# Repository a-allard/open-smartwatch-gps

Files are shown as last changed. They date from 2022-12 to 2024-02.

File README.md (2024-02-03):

# Open-Smartwatch KiCAD files

Repo for kicad schematic, board and gerber files. This project is in development and is not ready for release.

If all you want to know is how to build skip down to [Build Info](##Build Info)

#### Forking to move forward

The [original project ](https://github.com/Open-Smartwatch/open-smartwatch-gps) seems to have lost some momentum on development.  There is an [issue here](https://github.com/Open-Smartwatch/open-smartwatch-gps/issues/10) to discuss merging these changes into the original project.  One of the goals of this fork and update is to minimize any serious changes to [the os](https://github.com/Open-Smartwatch/open-smartwatch-os).  If all goes well, the OS should be able to be dropped on here with little to no modifications.  (that is the goal time will tell for sure.)

Right now this is a 2 layer design.  If this works it will greatly reduce the overall cost.  Have to see how this performs.

## Tools

To view/modify the files from this repository install [KiCAD](https://kicad.org).  You'll need version 7.0 or higher.  This will be bumped in Janurary of 2024 to KiCad 8.0.

All footprints, schematic symbols and 3d models should be self contained winthin the project.  This means you should be able to open the kicad project anywhere with or without the default kicad libraries and play with things without worry about missing pieces.

## Schematic
Updated as of 10/20/2023.  May change but if it does it should be minor changes.

Update on 1/7/2024.... Happy New Year to all!  Been quite for awhile as getting boards built and tested took quite a while.  Found a few issues.  Working on fixing them before another spin.  Probably be respinning sometime around May...?

Schematic

## Plots

Top
Bottom

## Build Info

To get some raw PCBs the best way would be [pcbway](https://pcbway.com).  Once this project has been built and tested the design will be published on pcbway for anyone to order with a couple clicks.

Next you'll have to either build this yourself or get these fabricated.  If you want to get the boards fabricated pcbway does a decent job.  You'll have to export the position files and put the BOM in pcbway format.

If you choose to solder these youself the smallest components are 0402 and QFNs.  Not the most friendly but can be done with a decent soldering iron.

### BOM

NOTE: **This is a preliminary BOM**  After testing this could change some.

[HTML BOM](https://github.com/a-allard/open-smartwatch-gps/blob/master/bom/OSW_GPS_Rev-4.0.html)  (best to download for a pretty view)

For actual parts you'll need
* [Digi-Key cart](https://www.digikey.com/short/5wz73v93) with most everything needed for a build of 1.
* [Display](https://www.buydisplay.com/1-28-inch-tft-lcd-display-240x240-round-circle-screen-for-smart-watch)
* A LiPo battery (Has not yet been selected but you should be able to power this from USB for initial debugging.  Any generic lipo should work just make sure the pinout works with the connector)

Total cost from DK ~$55.  The display is ~$15 including shipping.  With a battery this should bring the total BOM cost per watch to about ~$110 including boards from pcbway.com.  Note this is for a single watch but you'll have to order 5 boards from pcbway.com

Don't forget to get some decent fine solder while or solder paste as you will need it!

If you like this project, please consider supporting my open source projects through: "Buy Me A Coffee" (https://www.buymeacoffee.com/hwee)

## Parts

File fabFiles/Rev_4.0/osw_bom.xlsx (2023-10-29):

Item | Qty | Reference(s) | MPN | Manufacturer
1 | 1 | C1 | GRM155C81C105KE11J | Murata Electronics
2 | 1 | C2 | CC0402KPX5R6BB104 | YAGEO
3 | 4 | C3, C4, C10, C11 | CC0402MRX5R6BB475 | YAGEO
4 | 1 | C5 | CC0402KPX5R6BB104 | YAGEO
5 | 5 | C6, C7, C8, C15, C16 | CC0402KPX5R6BB104 | YAGEO
6 | 1 | C9 | CC0402KPX5R6BB104 | YAGEO
7 | 1 | C12 | CC0402KPX5R6BB104 | YAGEO
8 | 2 | C17, C18 | GRM155C81C105KE11J | Murata Electronics
9 | 1 | D1 | B0221USD-02D000154U1930
10 | 1 | J1 | B2B-EH-A
11 | 1 | J2 | MEM2067-02-180-00-A | GCT
12 | 1 | J3 | 2169890001 | Molex
13 | 1 | Q1 | T2N7002AK,LM
14 | 2 | R1, R19 | RC0402FR-07470RL | YAGEO
15 | 4 | R2, R3, R5, R12 | RC0402JR-071KL | YAGEO
16 | 12 | R4, R6, R7, R8, R9, R10, R11, R13, R16, R17, R20, R21 | RC0402DR-0710KL | YAGEO
17 | 1 | R14 | RC0402JR-0756KL | YAGEO
18 | 1 | R15 | RC0402FR-070RL | YAGEO
19 | 1 | R18 | RC0402FR-135K6L | YAGEO
20 | 4 | SW1, SW2, SW3, SW4 | EVQ-P7J01P | Panasonic Electronic Components
21 | 1 | U1 | L96-M33 | Quectel Wireless Solutions Co., Ltd
22 | 1 | U2 | TPS22933ARSET | Texas Instruments
23 | 1 | U3 | ESP32-MINI-1-N4 | Espressif Systems
24 | 1 | U4 | MCP73831T-2ACI/OT | Microchip Technology
25 | 2 | U5, U7 | MIC5504-3.3YMT-TZ | Microchip Technology
26 | 1 | U6 | FT234XD-R | FTDI
27 | 1 | U8 | 23K256T-I/SN | Microchip
28 | 1 | U9 | PCF85063ATL/1,118
29 | 1 | U10 | BMA400 | Bosch Sensortec
30 | 1 | U12 | IP4234CZ6,125
31 | 1 | U13 | BH1792GLC-E2

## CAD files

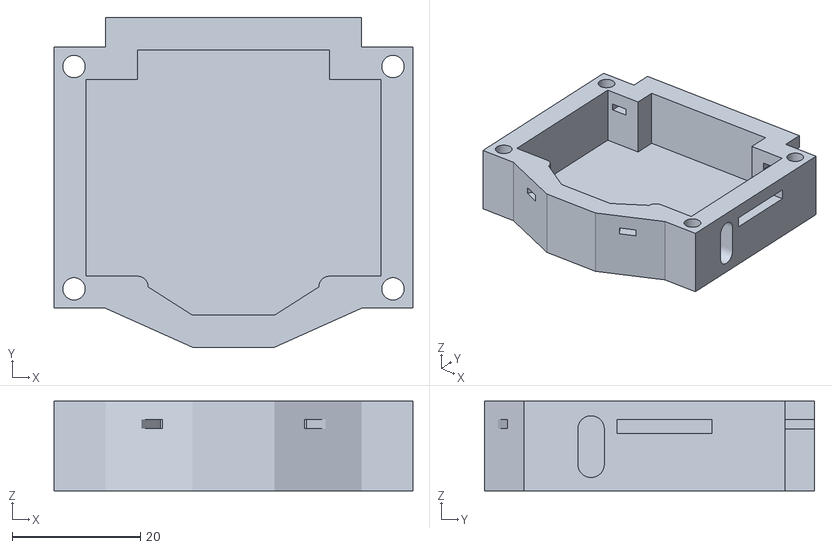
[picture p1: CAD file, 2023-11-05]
3dCAD_Source/mainCase.stl
56.0 x 51.4 x 14.0

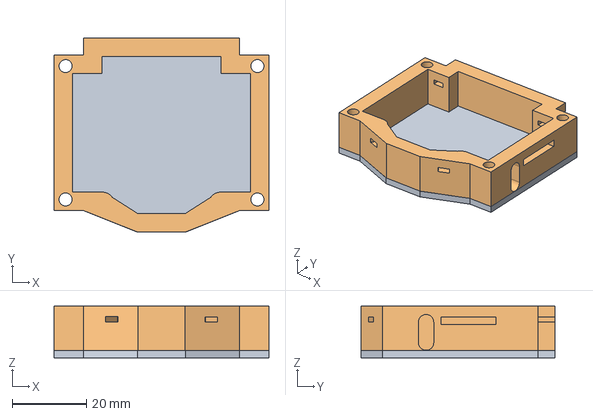
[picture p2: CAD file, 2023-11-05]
3dCAD_Source/watchCase.FCStd
58.0 x 52.4 x 14.0 mm

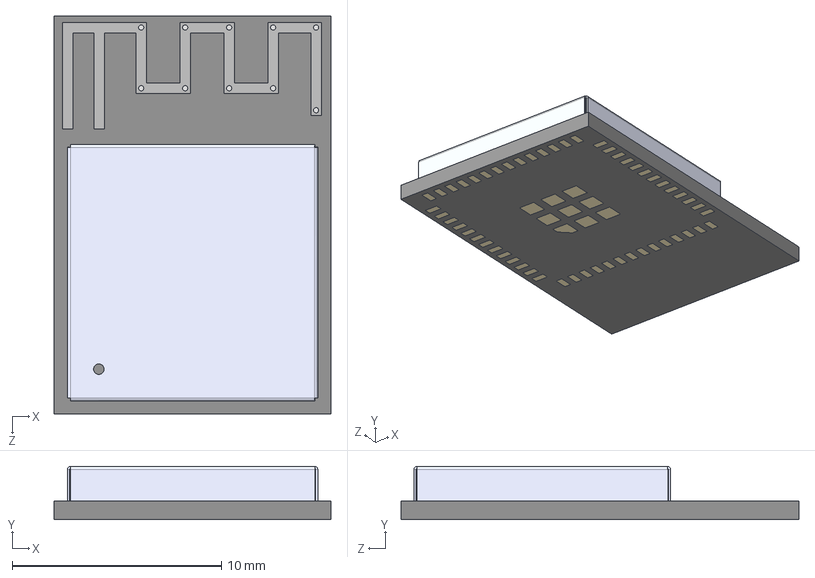
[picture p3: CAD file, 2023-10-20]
3dModels/ESP32-MINI-1-N4--3DModel-STEP-56544.STEP
13.2 x 2.55 x 19.0 mm

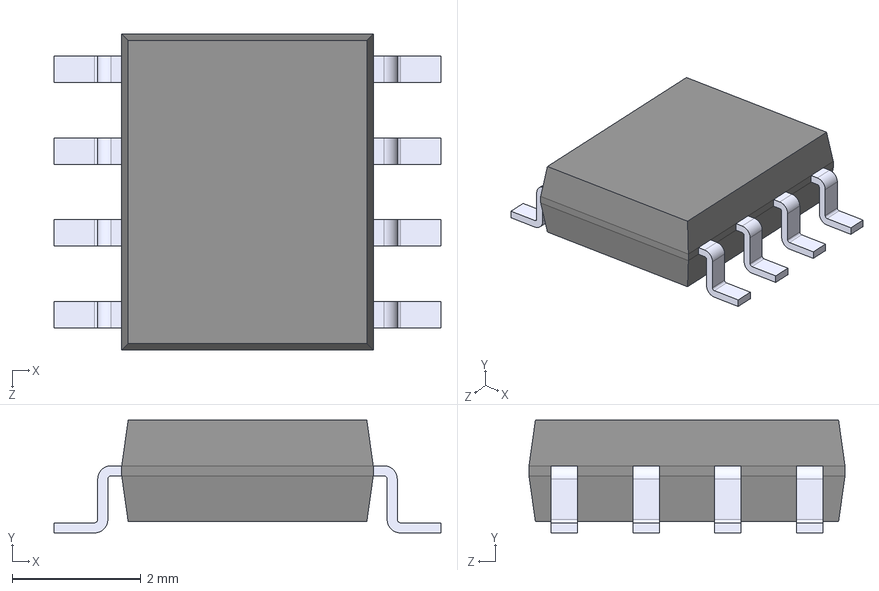
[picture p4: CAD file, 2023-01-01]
3dModels/23K256-I_SN.step
6.00 x 1.75 x 4.90 mm

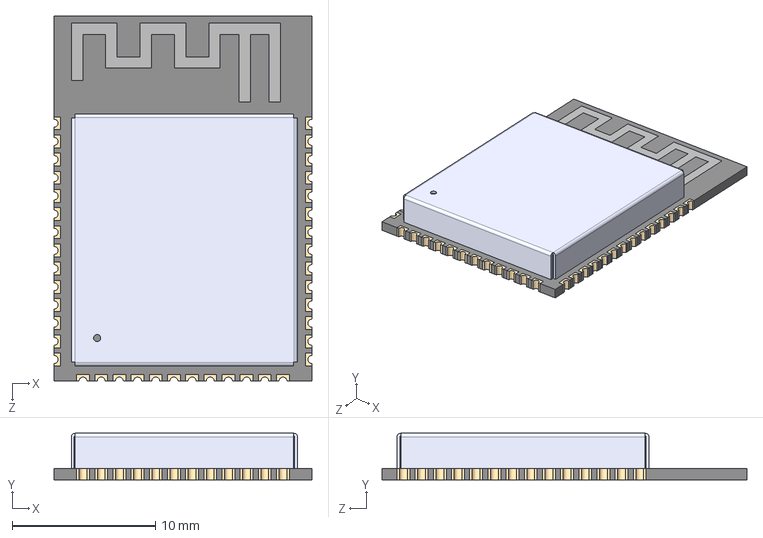
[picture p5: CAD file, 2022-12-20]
3dModels/ESP32-S3-WROOM-1.STEP
18.0 x 3.25 x 25.5 mm

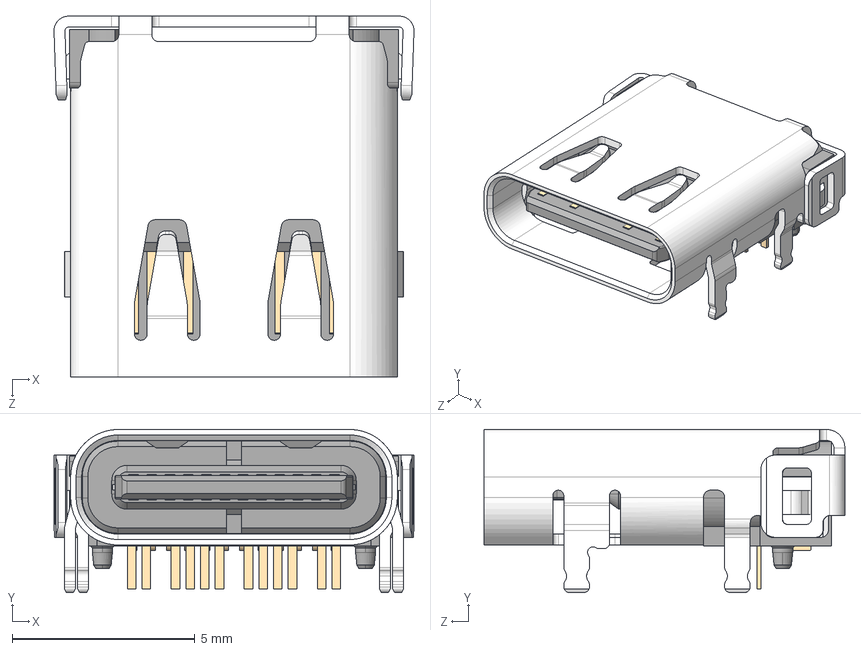
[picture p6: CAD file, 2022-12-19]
3dModels/USB4056-03-A_REVA.step
9.85 x 4.46 x 9.87 mm

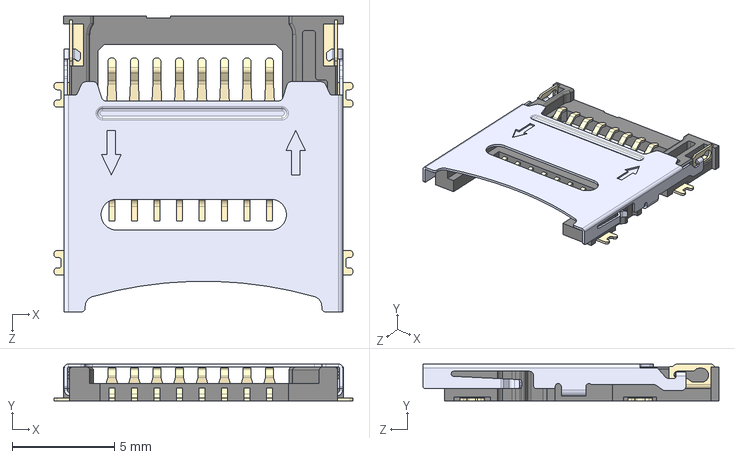
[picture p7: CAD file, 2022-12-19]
3dModels/MEM2067-02-180-00-A_REVB.step
14.6 x 1.80 x 14.5 mm

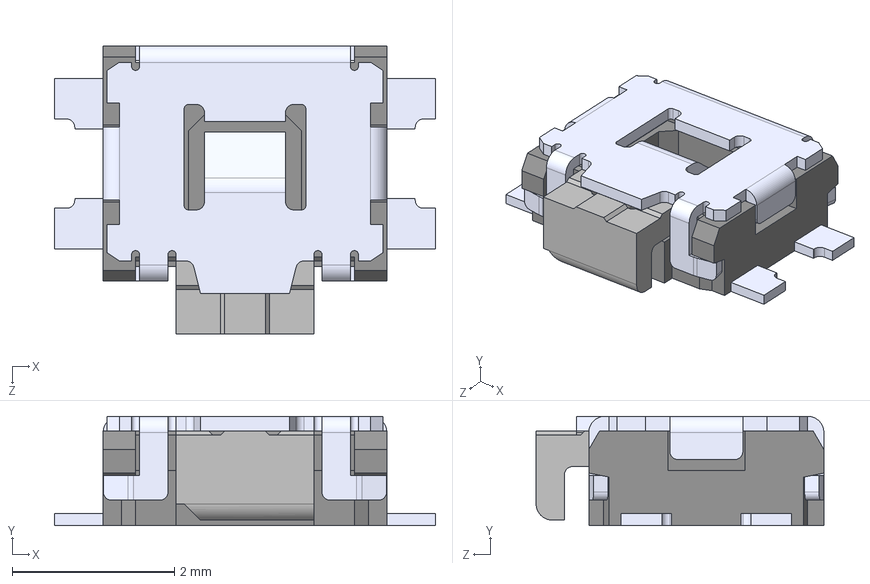
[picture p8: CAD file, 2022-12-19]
3dModels/EVQ-P7J01P.step
4.70 x 1.35 x 3.55 mm

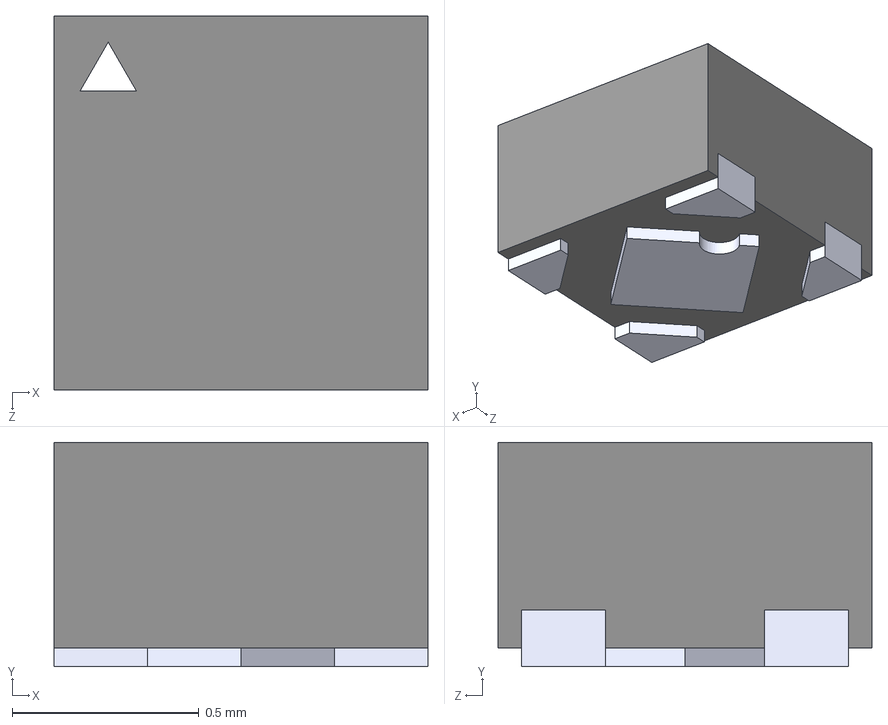
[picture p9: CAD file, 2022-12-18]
3dModels/VREG_MIC5504-3.3YMT-TZ.step
1.00 x 0.6 x 1.00 mm

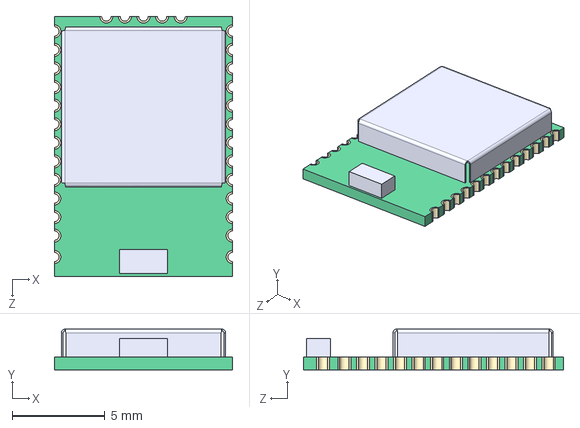
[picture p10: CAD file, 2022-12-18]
3dModels/L96-M33.step
9.60 x 2.20 x 14.0 mm

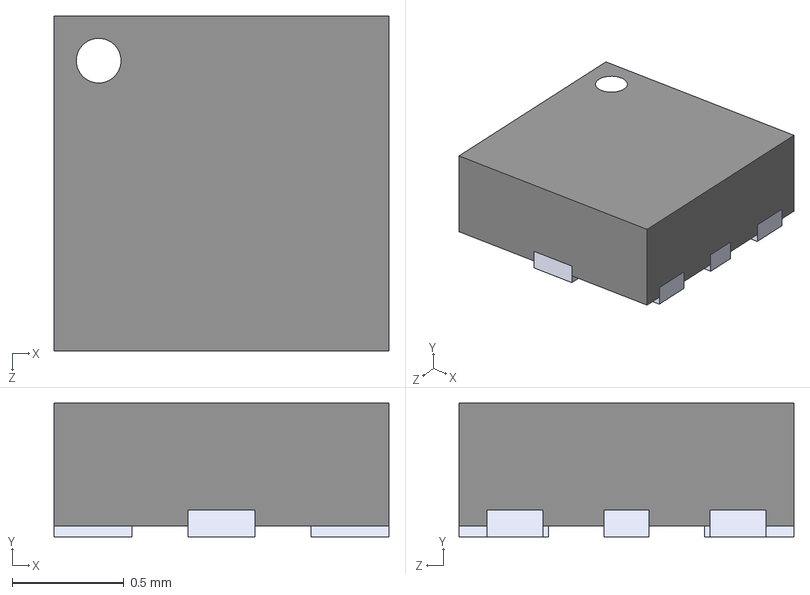
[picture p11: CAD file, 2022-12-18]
3dModels/uqfn_1p5x1p5_8_tps22933.step
1.50 x 0.6 x 1.50 mm

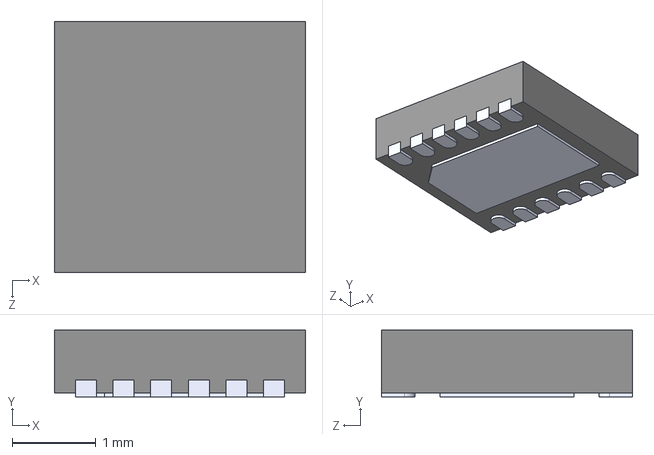
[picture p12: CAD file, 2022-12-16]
3dModels/FT234XD-R--3DModel-STEP-1.STEP
3.00 x 0.8 x 3.00 mm

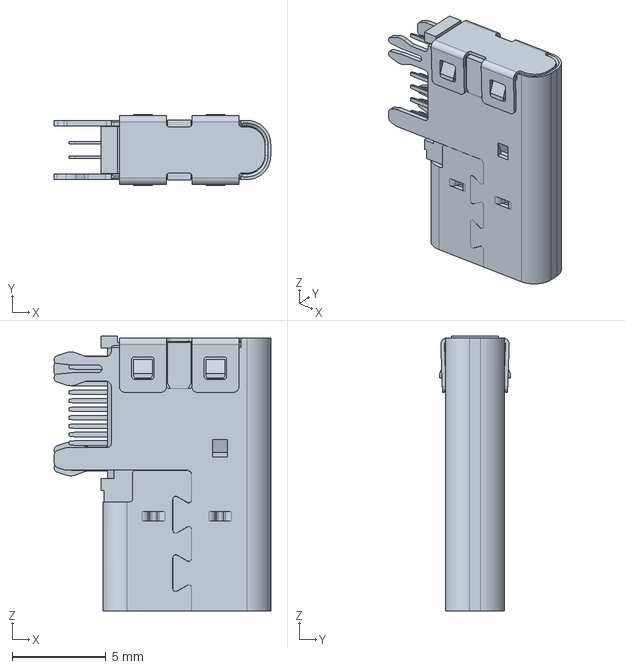
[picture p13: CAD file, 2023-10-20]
3dModels/2169890001.stp
11.5 x 3.76 x 14.7 mm

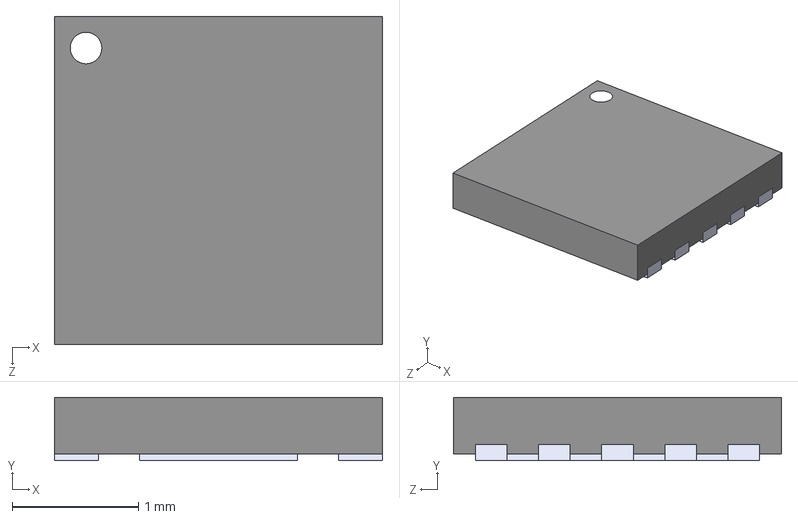
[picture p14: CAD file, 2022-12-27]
3dModels/PCF85063ATL_1_118.step
2.60 x 0.5 x 2.60 mm

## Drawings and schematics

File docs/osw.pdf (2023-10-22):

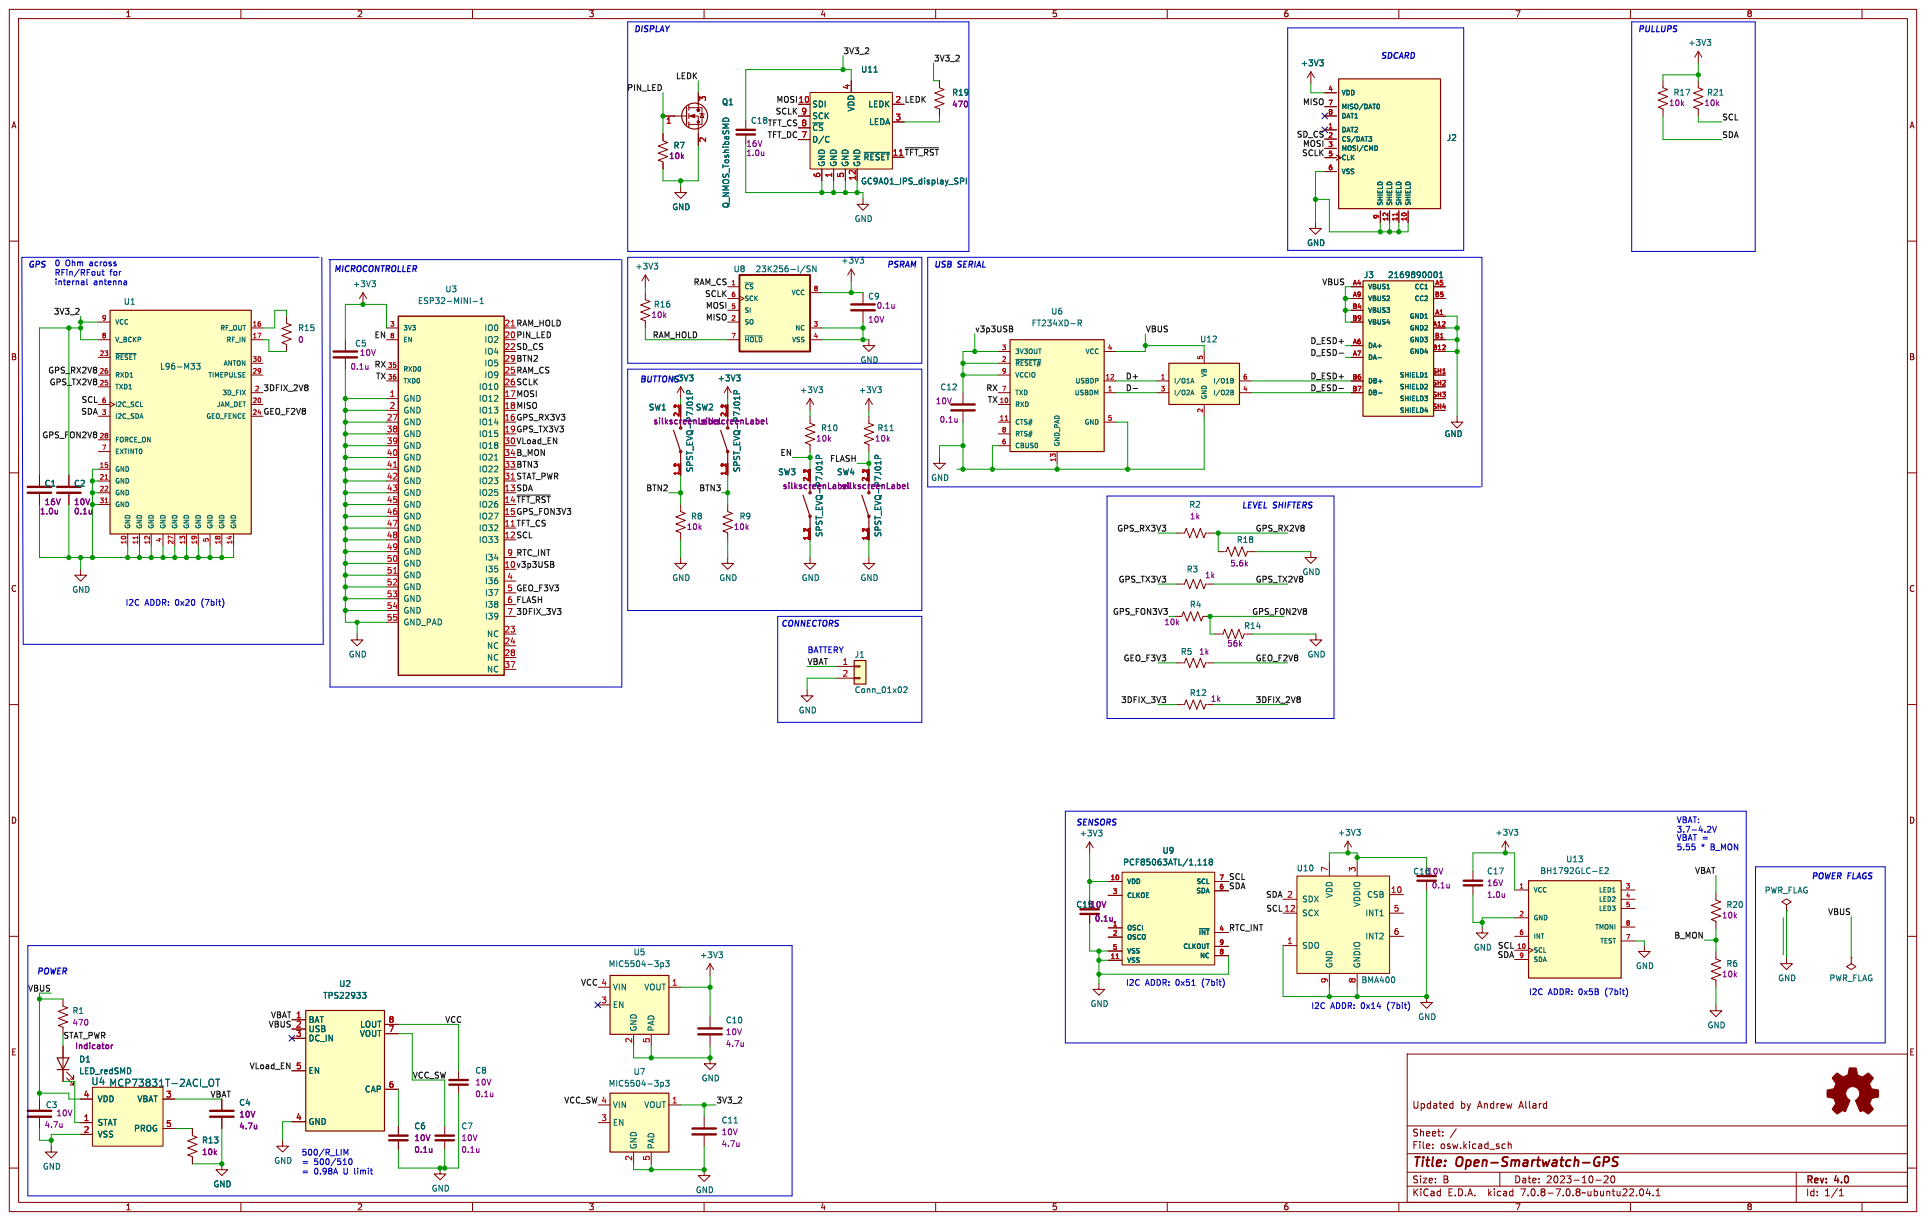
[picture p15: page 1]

9 U10 BMA400 1_12 2_12SW2 SPST_EVQ-P7J01P silkscreenLabel 1_12 2_12SW1 SPST_EVQ-P7J01P silkscreenLabel +3V3 USBDM 1 RXD 10 CTS# 11 USBDP 12 GND_PAD 13 ~{RESET#} 2

I36 4 GND 40 GND 41 GND 42 GND 43 GND 45 GND 46 GND 47 GND 48 GND 49 GND 50 GND 51 GND 52 GND 53 GND 54 GND_PAD 55 GND 1
IO15 19 GND 2

Id: 1/1 Title: Open-Smartwatch-GPS

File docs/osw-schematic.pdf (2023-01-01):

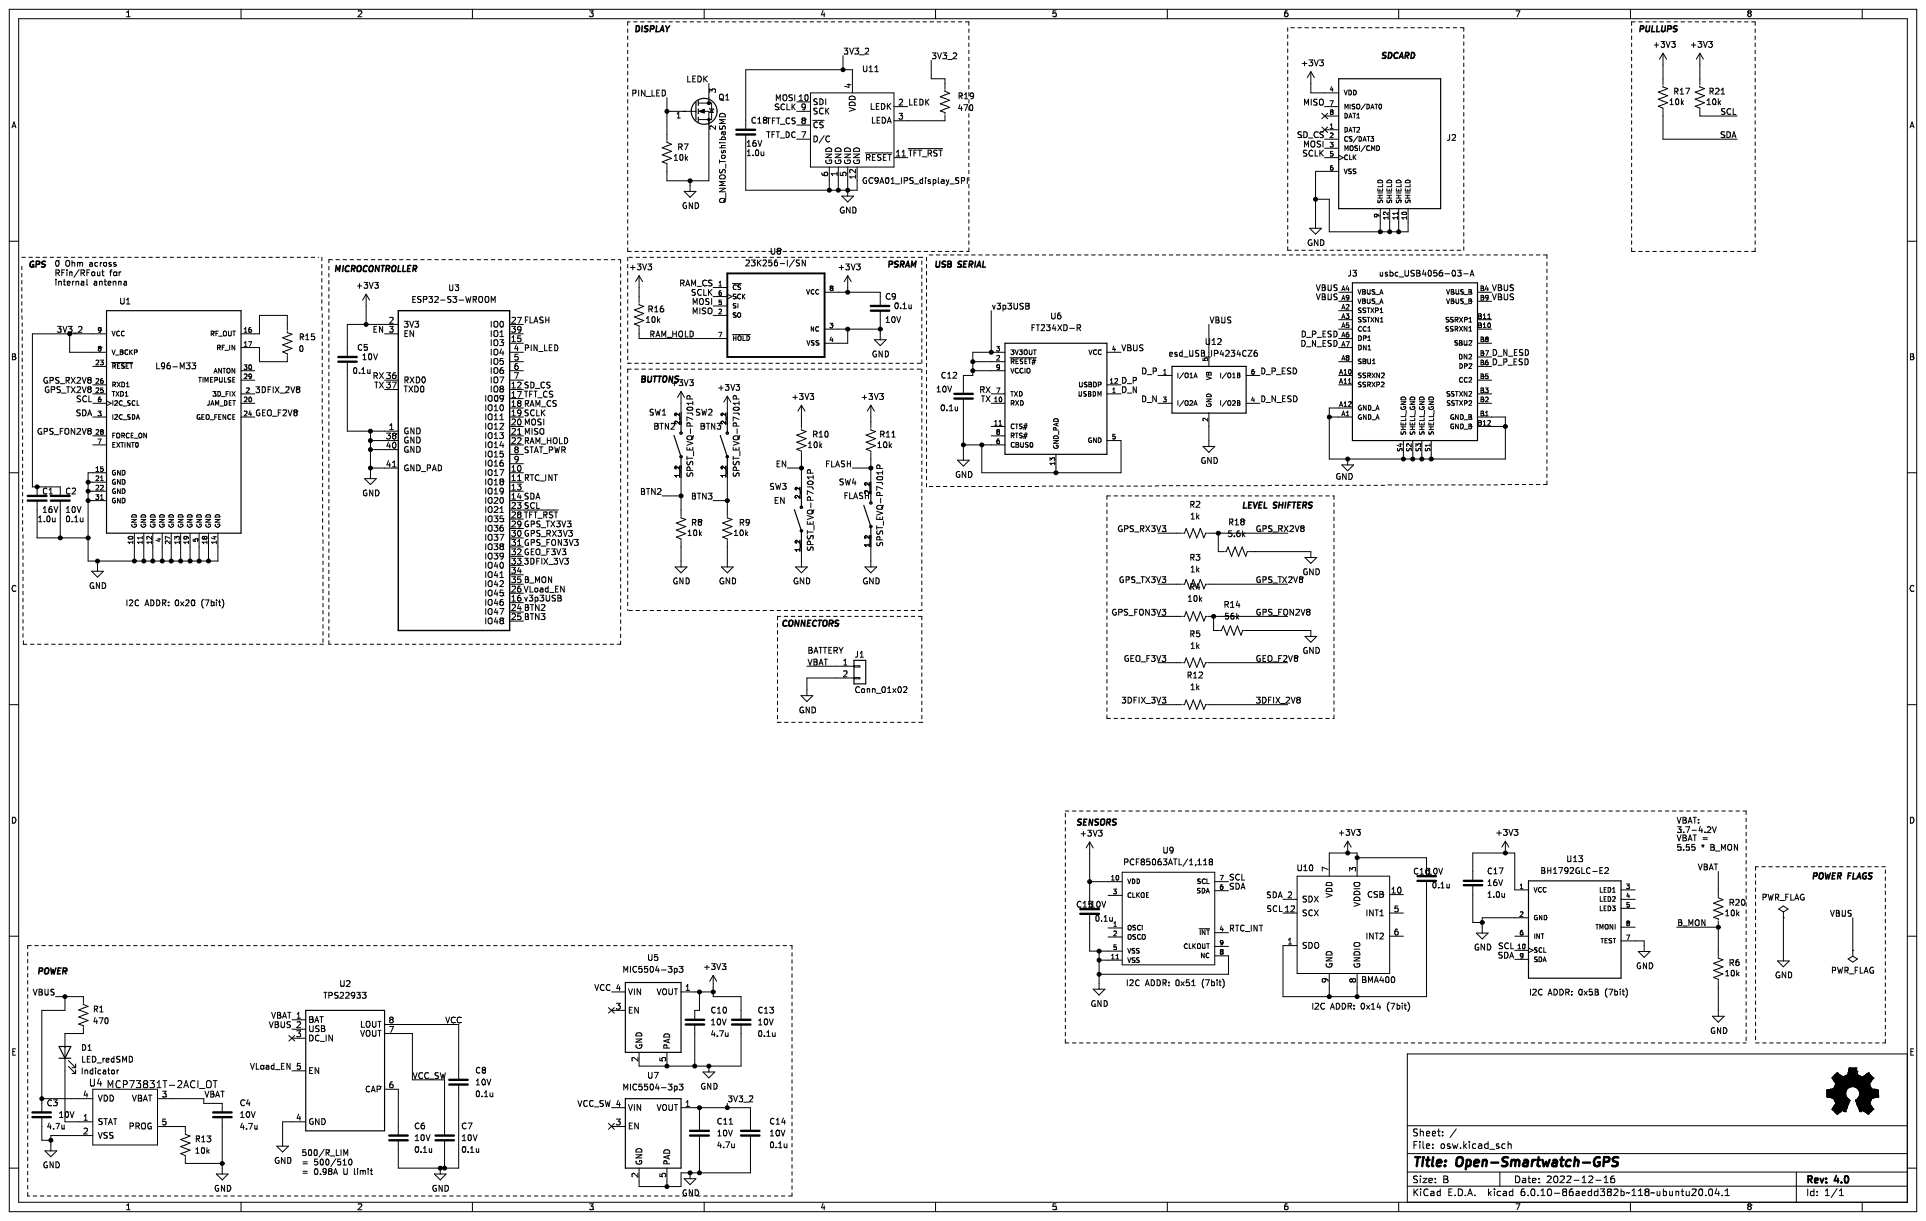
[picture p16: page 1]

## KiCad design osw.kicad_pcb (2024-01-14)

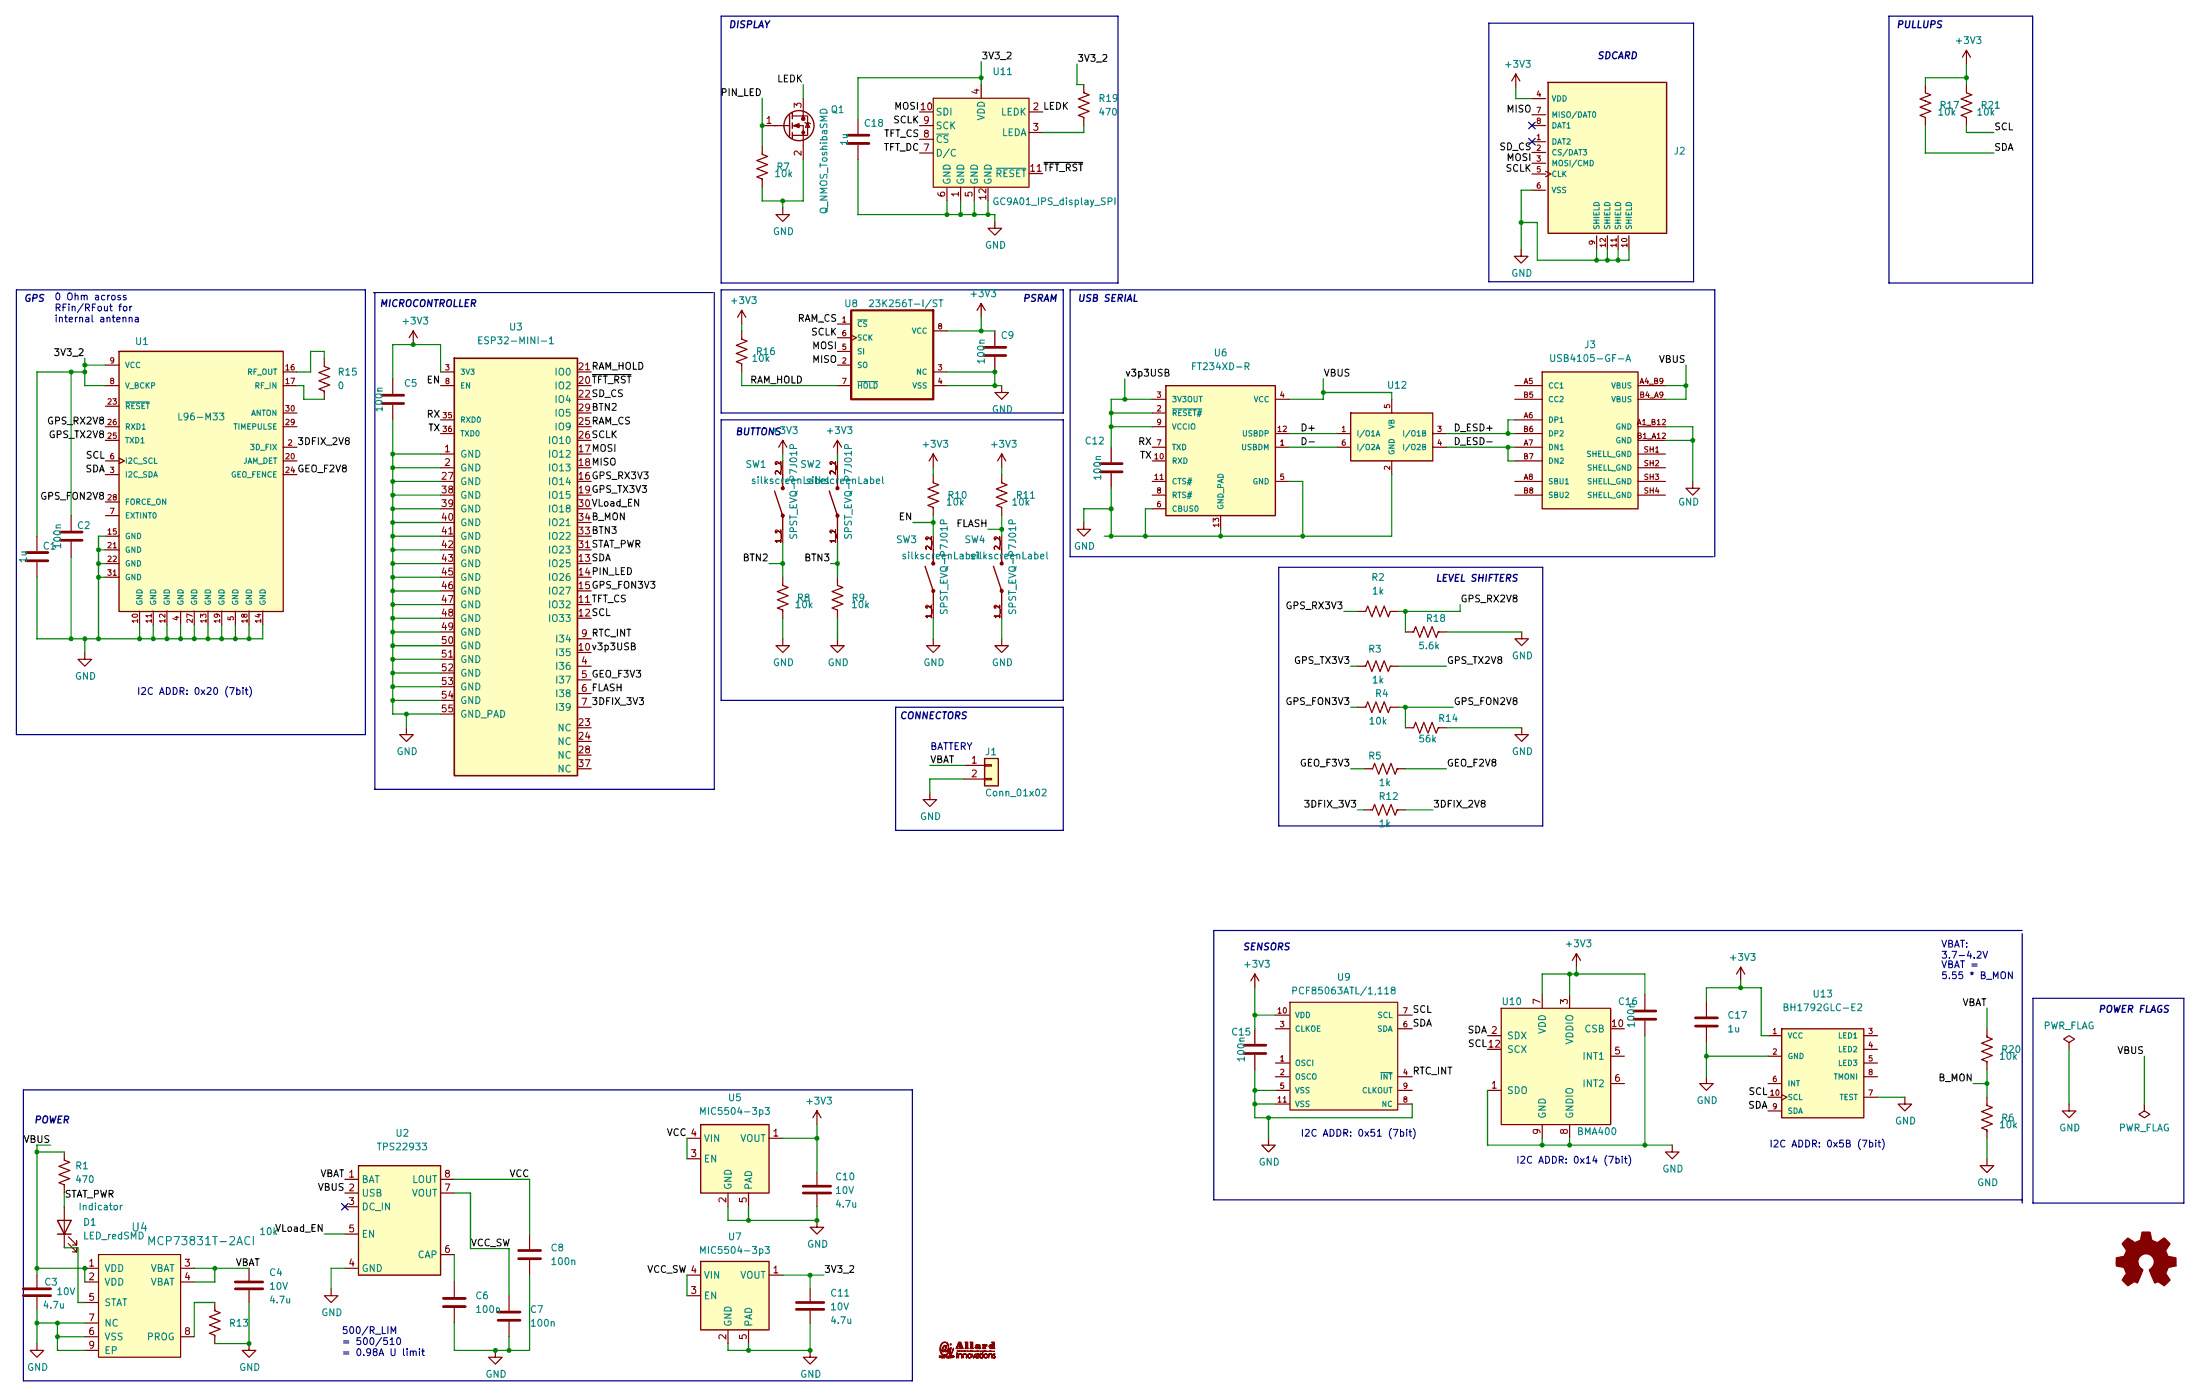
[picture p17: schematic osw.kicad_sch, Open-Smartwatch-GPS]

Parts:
C1, C17, C18: 1u; CAPC100X50X60L25N; Voltage 10V; Tolerance 10%; MPN GRM155Z71A105KE01J; DigiKey_PN 490-GRM155Z71A105KE01JCT-ND
C2, C5, C6, C7, C8, C9, C12, C15, C16: 100n; CAPC100X50X55L25N; Voltage 50V; Tolerance 10%; MPN GRM155R71H104KE14J; DigiKey_PN 490-13342-1-ND
C3, C4, C10, C11: cap0402_4p7u10V; C_0402_1005Metric_osw; Voltage 10V; MPN CC0402MRX5R6BB475; DigiKey_PN 311-1734-1-ND
D1: LED_redSMD; Harvatek_LED_osw; MPN B0221USD-02D000154U1930; DigiKey_PN 3147-B0221USD-02D000154U1930CT-ND
G1: LOGO; aiLogo
J1: Conn_01x02; PinHeader_1x02_P2.54mm_Vertical; MPN B2B-EH-A; DigiKey_PN 455-B2B-EH-A-ND
J2: microSD_MEM2067-02-180-00-A_REVB; GCT_MEM2067-02-180-00-A_REVB; MPN MEM2067-02-180-00-A; Mouser_PN 640-MEM20670218000A
J3: USB4105-GF-A; GCT_USB4105-GF-A; MPN USB4105-GF-A
Q1: Q_NMOS_ToshibaSMD; SOT23-3P95_240X105L35X42L; MPN T2N7002AK,LM; DigiKey_PN T2N7002AKLMCT-ND
R1, R19: res0402_470; R_0402_1005Metric_osw; MPN RC0402FR-07470RL; DigiKey_PN 311-470LRCT-ND
R2, R3, R5, R12: 1k; RESC100X50X40L25N; Tolerance 1%; MPN ERJ-2RKF1001X; DigiKey_PN P1.00KLCT-ND
R4, R6, R7, R8, R9, R10, R11, R13, R16, R17, R20, R21: 10k; RESC100X50X40L25N; Tolerance 1%; MPN ERJ-2RKF1002X; DigiKey_PN P10.0KLCT-ND
R14: res0402_56k; R_0402_1005Metric_osw; MPN RC0402JR-0756KL; DigiKey_PN 311-56KJRCT-ND
R15: res0402_0; R_0402_1005Metric_osw; MPN RC0402FR-070RL; DigiKey_PN 311-0.0LRCT-ND
R18: res0402_5p6k; R_0402_1005Metric_osw; MPN RC0402FR-135K6L; DigiKey_PN 13-RC0402FR-135K6LCT-ND
SW1, SW2, SW3, SW4: SPST_EVQ-P7J01P; SW_EVQ-P7J01P; MPN EVQ-P7J01P; Mouser_PN 667-EVQP7J01P
U1: L96-M33; XCVR_L96-M33; Mouser_PN 277-L96-M33; DigiKey_PN 2958-L96-M33CT-ND
U2: TPS22933; uqfn_1p5x1p5_8_tps22933; MPN TPS22933ARSET; DigiKey_PN 296-TPS22933ARSETCT-ND
U3: ESP32-MINI-1; XCVR_ESP32-MINI-1; Mouser_PN 356-ESP32-MINI1PH3Q0; DigiKey_PN 1965-ESP32-MINI-1-N4CT-ND
U4: MCP73831T-2ACI; PSON9P50_200X300X80L40X25T135X125L; MPN MCP73831T-2ACI/MC; DigiKey_PN MCP73831T-2ACI/MCCT-ND
U5, U7: MIC5504-3p3; VREG_MIC5504-3.3YMT-TZ; MPN MIC5504-3.3YMT-TZ; DigiKey_PN 576-4310-1-ND
U6: FT234XD-R; SON45P300X300X80-13N; MPN FT234XD-R; DigiKey_PN 768-1178-1-ND
U8: 23K256T-I/ST; SOP8P65_300X640X120L47X24L; MPN 23K256T-I/ST; DigiKey_PN 23K256T-I/STCT-ND
U9: PCF85063ATL/1,118; 10-DFN(2.6X2.6)_PCF85063A; MPN PCF85063ATL/1,118; DigiKey_PN 568-10235-1-ND
U10: BMA400; LGA-12_2x2mm_P0.5mm; MPN BMA400; DigiKey_PN 828-1081-1-ND
U11: GC9A01_IPS_display_SPI; GC9A01_IPS_display_under
U12: esd_USB_IP4234CZ6; SOT23-6P95_275X110L45X32N; MPN IP4234CZ6,125; DigiKey_PN 1727-4717-1-ND
U13: BH1792GLC-E2; XDCR_BH1792GLC-E2; MPN BH1792GLC-E2; DigiKey_PN BH1792GLC-E2CT-ND

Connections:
+3V3: C5.1, C9.1, C10.1, C15.1, C16.1, C17.1, J2.4 (VDD), R10.1, R11.1, R16.1, R17.1, R21.1, SW1.2_1, SW1.2_2, SW2.2_1, SW2.2_2, U3.3 (3V3), U5.1 (VOUT), U8.8 (VCC), U9.10 (VDD), U10.3 (VDDIO), U10.7 (VDD), U13.1 (VCC)
/3DFIX_2V8: R12.2, U1.2 (3D_FIX)
/3DFIX_3V3: R12.1, U3.7 (I39)
/3V3_2: C1.1, C2.1, C11.1, C18.1, R19.1, U1.8 (V_BCKP), U1.9 (VCC), U7.1 (VOUT), U11.4 (VDD)
/BTN2: R8.1, SW1.1_1, SW1.1_2, U3.29 (IO5)
/BTN3: R9.1, SW2.1_1, SW2.1_2, U3.33 (IO22)
/B_MON: R6.1, R20.2, U3.34 (IO21)
/D+: U6.12 (USBDP), U12.1 (I/O1A)
/D-: U6.1 (USBDM), U12.6 (I/O2A)
/D_ESD+: J3.A6 (DP1), J3.B6 (DP2), U12.3 (I/O1B)
/D_ESD-: J3.A7 (DN1), J3.B7 (DN2), U12.4 (I/O2B)
/EN: R10.2, SW3.2_1, SW3.2_2, U3.8 (EN)
/FLASH: R11.2, SW4.2_1, SW4.2_2, U3.6 (I38)
/GEO_F2V8: R5.2, U1.24 (GEO_FENCE)
/GEO_F3V3: R5.1, U3.5 (I37)
/GPS_FON2V8: R4.2, R14.1, U1.28 (FORCE_ON)
/GPS_FON3V3: R4.1, U3.15 (IO27)
/GPS_RX2V8: R2.2, R18.1, U1.26 (RXD1)
/GPS_RX3V3: R2.1, U3.16 (IO14)
/GPS_TX2V8: R3.2, U1.25 (TXD1)
/GPS_TX3V3: R3.1, U3.19 (IO15)
/LEDK: Q1.3 (D), U11.2 (LEDK)
/MISO: J2.7 (MISO/DAT0), U3.18 (IO13), U8.2 (SO)
/MOSI: J2.3 (MOSI/CMD), U3.17 (IO12), U8.5 (SI), U11.10 (SDI)
/PIN_LED: Q1.1 (G), R7.1, U3.14 (IO26)
/RAM_CS: U3.25 (IO9), U8.1 (~CS)
/RAM_HOLD: R16.2, U3.21 (IO0), U8.7 (~HOLD)
/RTC_INT: U3.9 (I34), U9.4 (~INT)
/RX: U3.35 (RXD0), U6.7 (TXD)
/SCL: R21.2, U1.6 (I2C_SCL), U3.12 (IO33), U9.7 (SCL), U10.12 (SCX), U13.10 (SCL)
/SCLK: J2.5 (CLK), U3.26 (IO10), U8.6 (SCK), U11.9 (SCK)
/SDA: R17.2, U1.3 (I2C_SDA), U3.13 (IO25), U9.6 (SDA), U10.2 (SDX), U13.9 (SDA)
/SD_CS: J2.2 (CS/DAT3), U3.22 (IO4)
/STAT_PWR: D1.2 (A), R1.1, U3.31 (IO23)
/TFT_CS: U3.11 (IO32), U11.8 (~CS)
/TFT_DC: U11.7 (D/C)
/TX: U3.36 (TXD0), U6.10 (RXD)
/VBAT: C4.1, J1.1, R20.1, U2.1 (BAT), U4.3 (VBAT), U4.4 (VBAT)
/VBUS: C3.2, J3.A4_B9 (VBUS), J3.B4_A9 (VBUS), R1.2, U2.2 (USB), U4.1 (VDD), U4.2 (VDD), U6.4 (VCC), U12.5 (VB)
/VCC: C8.1, U2.8 (LOUT), U5.3 (EN), U5.4 (VIN)
/VCC_SW: C7.1, U2.7 (VOUT), U7.3 (EN), U7.4 (VIN)
/VLoad_EN: U2.5 (EN), U3.30 (IO18)
/v3p3USB: C12.1, U3.10 (I35), U6.2 (~RESET#), U6.3 (3V3OUT), U6.9 (VCCIO)
/~TFT_RST: U3.20 (IO2), U11.11 (~RESET)
GND: C1.2, C2.2, C3.1, C4.2, C5.2, C6.2, C7.2, C8.2, C9.2, C10.2, C11.2, C12.2, C15.2, C16.2, C17.2, C18.2, J1.2, J2.6 (VSS), J2.9 (SHIELD), J2.10 (SHIELD), J2.11 (SHIELD), J2.12 (SHIELD), J3.A1_B12 (GND), J3.B1_A12 (GND), Q1.2 (S), R6.2, R7.2, R8.2, R9.2, R13.2, R14.2, R18.2, SW3.1_1, SW3.1_2, SW4.1_1, SW4.1_2, U1.4 (GND), U1.5 (GND), U1.10 (GND), U1.11 (GND), U1.12 (GND), U1.13 (GND), U1.14 (GND), U1.15 (GND), U1.18 (GND), U1.19 (GND), U1.21 (GND), U1.22 (GND), U1.27 (GND), U1.31 (GND), U2.4 (GND), U3.1 (GND), U3.2 (GND), U3.27 (GND), U3.38 (GND), U3.39 (GND), U3.40 (GND), U3.41 (GND), U3.42 (GND), U3.43 (GND), U3.45 (GND), U3.46 (GND), U3.47 (GND), U3.48 (GND), U3.49 (GND), U3.50 (GND), U3.51 (GND), U3.52 (GND), U3.53 (GND), U3.54 (GND), U3.55 (GND_PAD), U4.6 (VSS), U4.7 (NC), U4.9 (EP), U5.2 (GND), U5.5 (PAD), U6.5 (GND), U6.6 (CBUS0), U6.13 (GND_PAD), U7.2 (GND), U7.5 (PAD), U8.3 (NC), U8.4 (VSS), U9.5 (VSS), U9.8 (NC), U9.11 (VSS), U10.1 (SDO), U10.8 (GNDIO), U10.9 (GND), U11.1 (GND), U11.5 (GND), U11.6 (GND), U11.12 (GND), U12.2 (GND), U13.2 (GND), U13.7 (TEST)
unnamed: D1.1 (K), U4.5 (STAT)
unnamed: R15.2, U1.17 (RF_IN)
unnamed: R15.1, U1.16 (RF_OUT)
unnamed: C6.1, U2.6 (CAP)
unnamed: R13.1, U4.8 (PROG)
unnamed: R19.2, U11.3 (LEDA)

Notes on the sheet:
SENSORS
LEVEL SHIFTERS
USB SERIAL
BATTERY
CONNECTORS
I2C ADDR: 0x51 (7bit)
VBAT: 3.7-4.2V
BUTTONS
I2C ADDR: 0x14 (7bit)
POWER
PSRAM
POWER FLAGS
PULLUPS
500/R_LIM = 500/510 = 0.98A U limit
GPS
0 Ohm across RFin/RFout for internal antenna
I2C ADDR: 0x20 (7bit)
MICROCONTROLLER
I2C ADDR: 0x5B (7bit)
DISPLAY
VBAT = 5.55 * B_MON
SDCARD

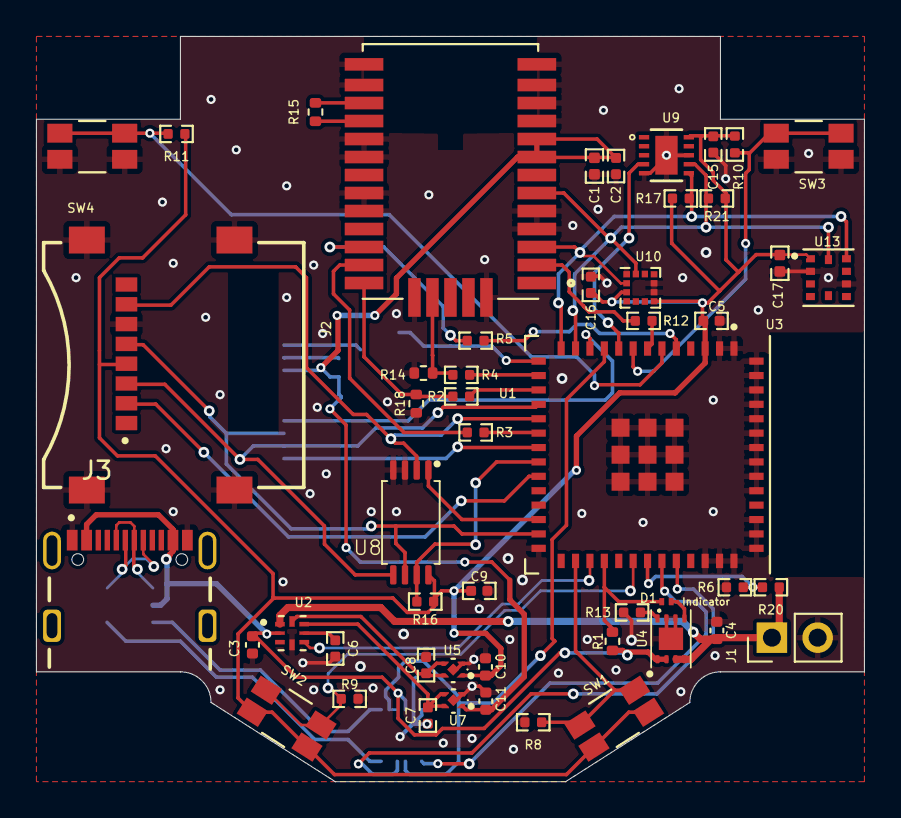
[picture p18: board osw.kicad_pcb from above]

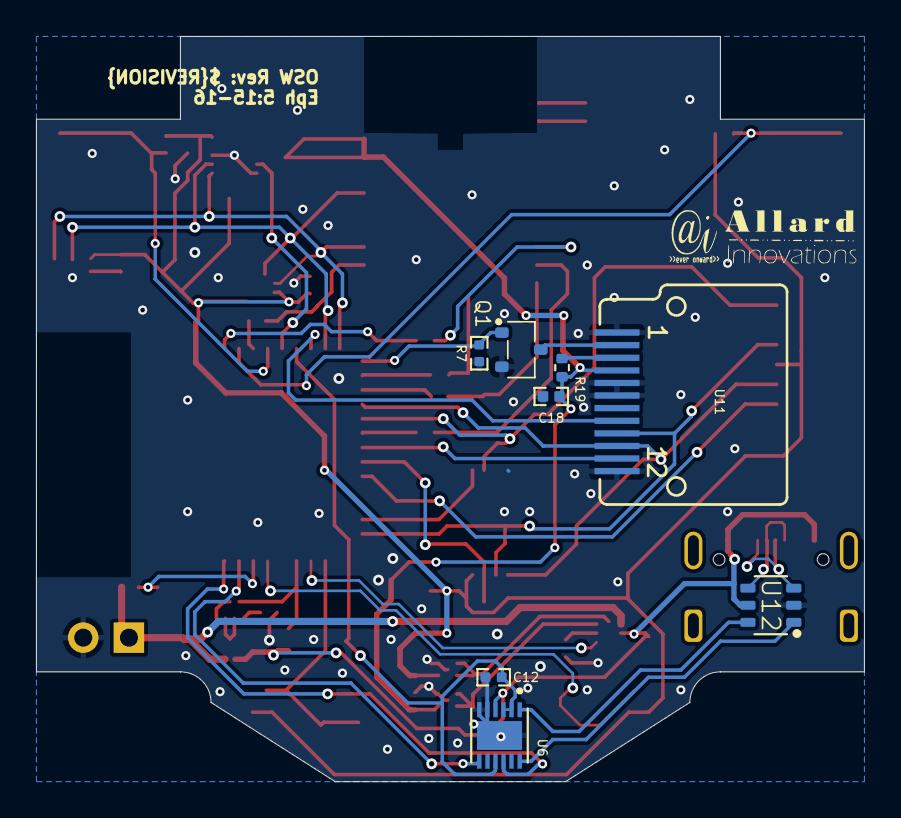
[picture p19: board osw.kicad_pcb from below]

Board: 2 copper layers, 46.0 x 41.4 mm, 60 parts (9 on the bottom side), 50 nets.

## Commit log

2022-12-15 Moving this to kicad 6 and looking at potential solutions to adding a buzzer and heart-rate monitor. Have to see if original repo owner is open to this.
    [osw.kicad_pcb, osw.kicad_sch, osw.sch]
2022-12-15 Updating the libs to kicad 6 as well.
    [osw.kicad_pcb]
2022-12-16 Moving all library items into this repo and adding full manf# info to all parts. Also adding new parts where some are now obsolete.
    [FT234XD-R--3DModel-STEP-1.STEP]
2022-12-18 Updates to the libs getting new parts for rev 4.
    [L96-M33.step, VREG_MIC5504-3.3YMT-TZ.step, osw.kicad_sch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]
2022-12-19 Continuing to update symbols and models and moving all symbols to metric grids.
    [EVQ-P7J01P.step, MEM2067-02-180-00-A_REVB.step, USB4056-03-A_REVA.step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]
2022-12-20 Updates to the libs to get more footprints and symbols added to this project.
2022-12-20 another step model for the model.
    [ESP32-S3-WROOM-1.STEP]
2022-12-20 Updates to the board and schematic.
    [osw.kicad_pcb, osw.kicad_sch]
2022-12-21 Adding a very small regulater for running everything.
    [osw.kicad_pcb, osw.kicad_sch]
2022-12-27 Updates to the libs and the schematic. Only need to update the battery charger a FET and a couple of resisters. After that this should be good to go to layout.
    [PCF85063ATL_1_118.step, osw.kicad_sch]
2022-12-27 A couple of new footprints in the lib.
2022-12-27 Updating the display connector footprint.
    [osw.kicad_pcb, osw.kicad_sch]
2022-12-31 Getting close to schemtatic done. Still have RAM to figure out and need to finish backlight driver FET. Otherwise schematiclly things are looking good.
    [osw.kicad_sch]
2023-01-01 Finished schematic. Ready to begin board layout.
    [23K256-I_SN.step, osw.kicad_pcb, osw.kicad_sch]
2023-01-01 Updating the docs for the schematic. May need to swap out the ESP chip as it is quite wide for the board layout....
    [osw.kicad_pcb, osw.kicad_sch]
2023-01-07 Updates to the schematic to use a smaller packaged ESP32.
    [osw.kicad_pcb, osw.kicad_sch]
2023-10-19 Getting back to this now that someone from the OSW community has mentioned this would be good.
    [osw.kicad_pcb, osw.kicad_sch]
2023-10-20 Working through some junk in the schematic. Got the board outline done and components all on the board. Very rough layout done. More work needed before traces start getting drawn.
    [2169890001.stp, ESP32-MINI-1-N4--3DModel-STEP-56544.STEP, osw.kicad_pcb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]
2023-10-20 Forgot to save board before last commit.
    [osw.kicad_pcb]
2023-10-21 Had to redo the schematic libs as goofball chose a bad grid size. Not a big deal.... But this will make any changes easier. Be ware if you update all symbols some will breakgit status!
    [osw.kicad_sch]
2023-10-21 Updates as the schematic is getting close to done.
2023-10-21 Updated dates.
    [osw.kicad_sch]
2023-10-21 Starting on the layout in ernest now.
    [osw.kicad_pcb, osw.kicad_sch]
2023-10-21 Adding more docs on the ESP32. If this works out well the ESP will get repined for layout sake.
    [osw.kicad_pcb, osw.kicad_sch]
2023-10-21 Updated ESP mod in schematic with better symbol.:
    [osw.kicad_sch]
2023-10-21 Updates to schematic and board.
    [osw.kicad_pcb, osw.kicad_sch]
2023-10-21 Added some more track sizes.
2023-10-21 Adding another kicad file.
2023-10-21 working on the layout.
    [osw.kicad_pcb, osw.kicad_sch]
2023-10-22 Added some dimensions to the layout and corrected all the edge cuts so the board is symetric.
    [osw.kicad_pcb]
2023-10-22 Repinned out the ESP32 to get a bit better layout.
    [osw.kicad_sch]
2023-10-22 Updates to several footprints as they were not quite correct. Finished layout. All done on a simple two layer board. Need to look over the design once more before ordering prototypes.
    [osw.kicad_pcb, osw.kicad_sch]
2023-10-22 Updating the schematic docs.
2023-10-22 Adding HTML BOM
2023-10-23 Optimizing the layout a bit.
    [osw.kicad_pcb]
2023-10-23 Adding some silkscreen dressup.
    [osw.kicad_pcb, osw.kicad_sch]
2023-10-24 Footprint looked a bit small... After looking at the datasheet turns out it was very too small. SHould be good now.
2023-10-24 Finishing up the board. Provided nothing jumps out looking through the DOCs later this should be good to order
    [osw.kicad_pcb, osw.kicad_sch]
2023-10-24 Updating the BOM with a good JST connector that should work for most LiPo batteries."
2023-10-24 Adding the BOM ini file so Allard doesn't have to remember to keep changing the settings.
2023-10-24 JST connector properties added to board layout for html bom generator.
    [osw.kicad_pcb]
2023-10-28 Updates for final fab
    [osw.kicad_pcb, osw.kicad_sch]
2023-10-29 Updating the repo with the actual fab files.
    [osw-B_Cu.gbr, osw-B_Mask.gbr, osw-B_Paste.gbr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]
2023-10-29 Removing the older rev gerbers. All fab stuff is now in fab folder.
    [osw-3V3_v.gbr, osw-B_Adhes_v.gbr, osw-B_CrtYd_v.gbr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]
2023-10-29 Adding some updates to the gitignore and movingh the bom to the fab folder.
    [osw_bom.xlsx]
2023-10-29 Adding plots of board.
2023-10-29 Adding pos files.
    [osw-bottom-pos.csv, osw-top-pos.csv]
2023-10-31 Adding another dimension to the layout for modeling the case.
    [osw.kicad_pcb]
2023-11-05 Adding a cad model for a basic case. Not sure it'll work
    [mainCase.stl, watchCase.FCStd]
2024-01-07 Corrected a library FP. Also corrected the fact the regulators need to be pulled up to work correctly. Rotated LCD FP so it folds correctly now. Only thing left is to find the nasty short that is cau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
    [osw.kicad_pcb, osw.kicad_sch]
2024-01-07 Update README.md
    Updating with current status.
2024-01-07 Fixing the ESD diode array that was mis-pinned.
    [osw.kicad_pcb, osw.kicad_sch]
2024-01-08 Adding a few comments about what to use in the next gen.
    [osw.kicad_sch]
2024-01-09 Updates to a bunch of symbols and the entire schematic now matches the libs.... Now onto fixing the short.
    [osw.kicad_pcb, osw.kicad_sch]
2024-01-09 Updating some FPs.
    [osw.kicad_pcb, osw.kicad_sch]
2024-01-10 Moving things to kicad 8.
    [osw.kicad_pcb]
2024-01-10 Updating the FP for a SOT23.
    [osw.kicad_pcb, osw.kicad_sch]
2024-01-12 Got USB connector chagned.
    [osw.kicad_pcb, osw.kicad_sch]
2024-01-14 Updating the layout to send to PCBway again....
    [osw.kicad_pcb]
